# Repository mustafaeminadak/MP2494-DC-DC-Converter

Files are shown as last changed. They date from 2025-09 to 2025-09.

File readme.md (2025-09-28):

# MP2494 DC-DC Converter

This repository contains the hardware design files for a **DC/DC Buck Converter** based on the **MP2494 Step-Down Regulator IC**. The design focuses on **Low EMI**, **High Efficiency**, and **Reliable PCB Layout Practices** to ensure stable operation. You will find resources such as datasheets, specifications, design considerations, schematics, layouts, and 3D previews of the board.  

## 📑 Datasheet  

The MP2494 is a **monolithic step-down switch mode converter**. It delivers up to **2A continuous output current** across a wide input voltage range with excellent load and line regulation.  

- Features low EMI signature with controlled switching edges.  
- Built-in protections: **cycle-by-cycle current limiting** and **thermal shutdown**.  
- Requires only a few standard external components.  
- Available in **SOIC8** and **SOIC8E** packages.  

The MP2494 uses a **current-mode control architecture**:  
- At the start of a cycle, the switch turns on, connecting the inductor to the input supply.  
- The inductor current is sensed and compared with the Error Amplifier output.  
- When the sensed current exceeds the control threshold, the switch is turned off.  
- A Schottky diode carries inductor current during the off cycle.  

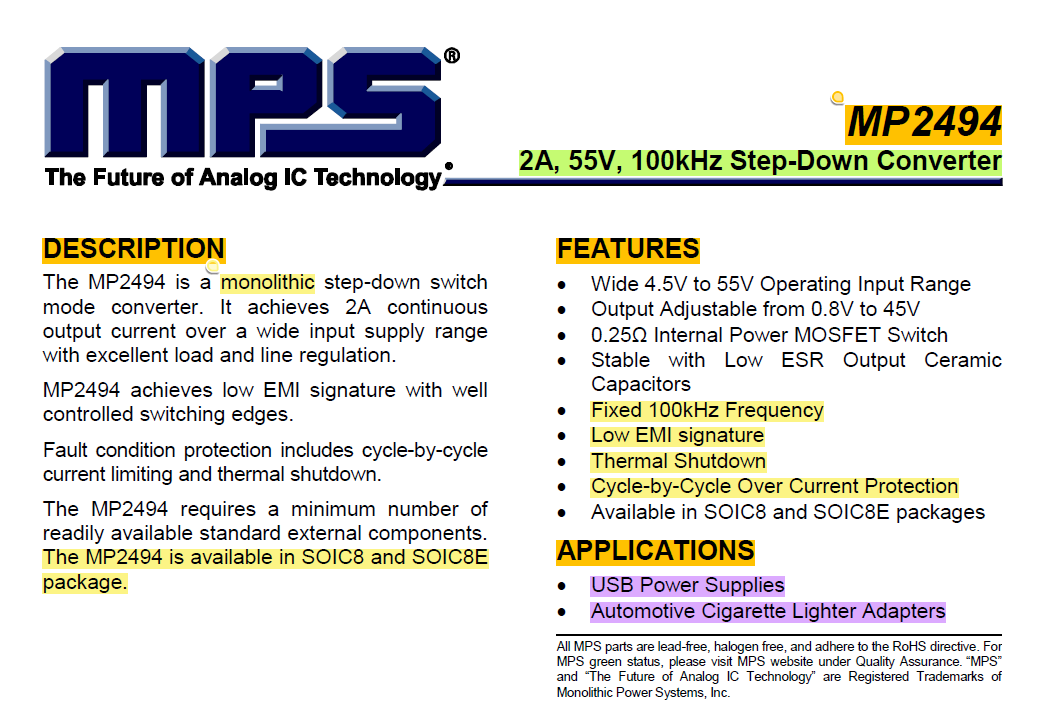
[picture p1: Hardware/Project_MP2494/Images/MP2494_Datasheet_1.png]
Datasheet Diagram_1

##
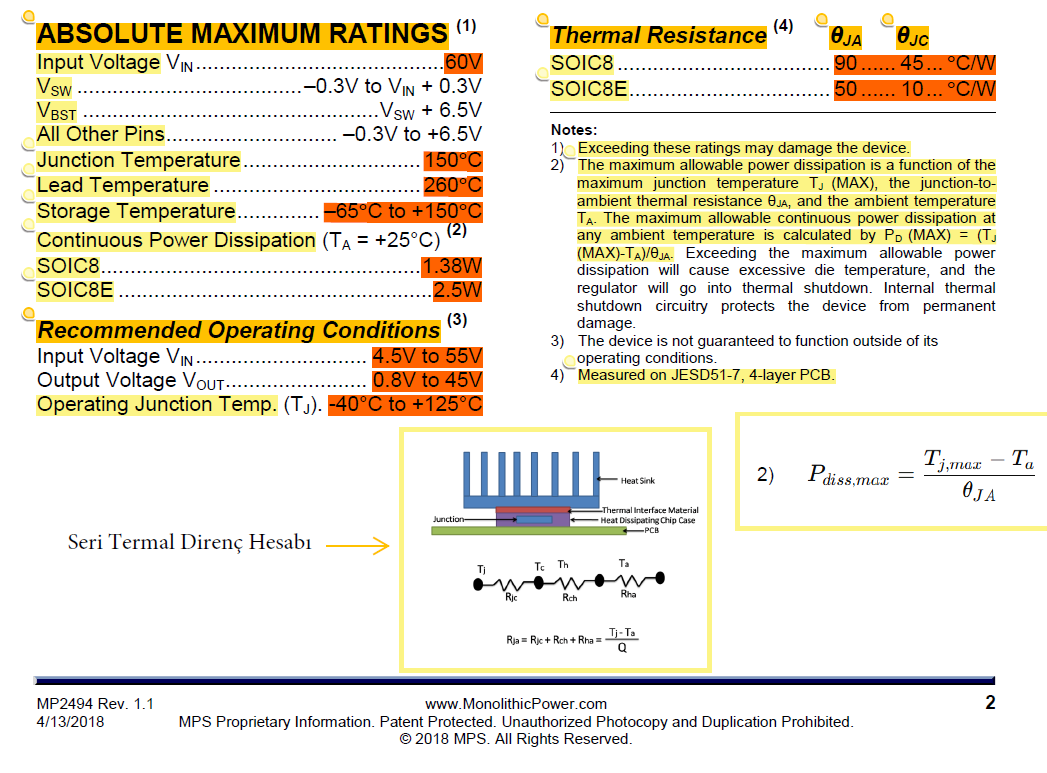
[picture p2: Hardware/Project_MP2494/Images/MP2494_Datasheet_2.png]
Datasheet Diagram_2


## ⚙️ Specifications

* Input Voltage Range: **10V – 48V**
* Nominal Voltage: **12V**
* Output Voltage: **5V**
* Output Current: **2A**
* Switching Frequency: **100kHz (typical)**
* Inductor Ripple Current: **38%**
* Slew Rate of Transient: **1 A/µs**
* Protection: **OCP, Thermal Shutdown**
* Efficiency (measured): **~85.75%**

# MPS Design Tool Simulation
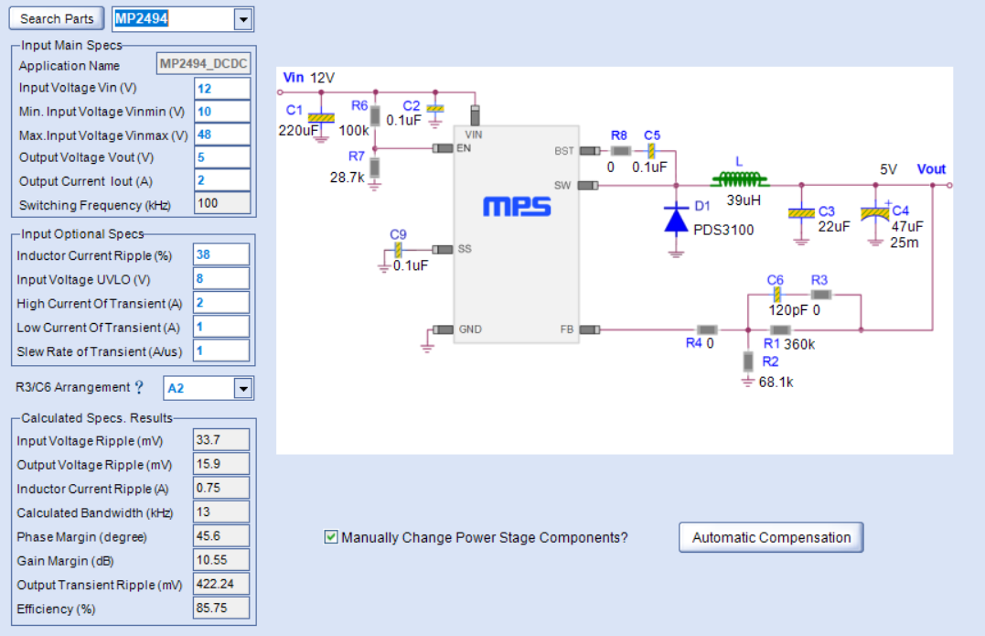
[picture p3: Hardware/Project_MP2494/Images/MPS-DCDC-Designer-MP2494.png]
Specifications


## 🛠️ Design Considerations

When designing the PCB, follow these layout guidelines for stable operation and reduced EMI:

1. Place the **input capacitor** and **freewheel diode** on the same PCB layer as the IC and as close as possible to the IC pins.
2. Use **thermal vias** if necessary to improve heat dissipation.
3. Place the **inductor close to the IC**, but it does not need to be as close as the input capacitor. Keep copper area for the switching node minimal to reduce noise radiation.
4. Place the **output capacitor close to the inductor**.
5. Keep the **ground return path** away from noise-sensitive components.

Additional Notes:

* For mounting holes, GND connection depends on mechanical and shielding needs.
* Edge plating is not required for all boards but can help in high-current, EMI-sensitive designs.
* The EN pin can be tied to VIN (always-on) or controlled via a resistor divider (optional R7).

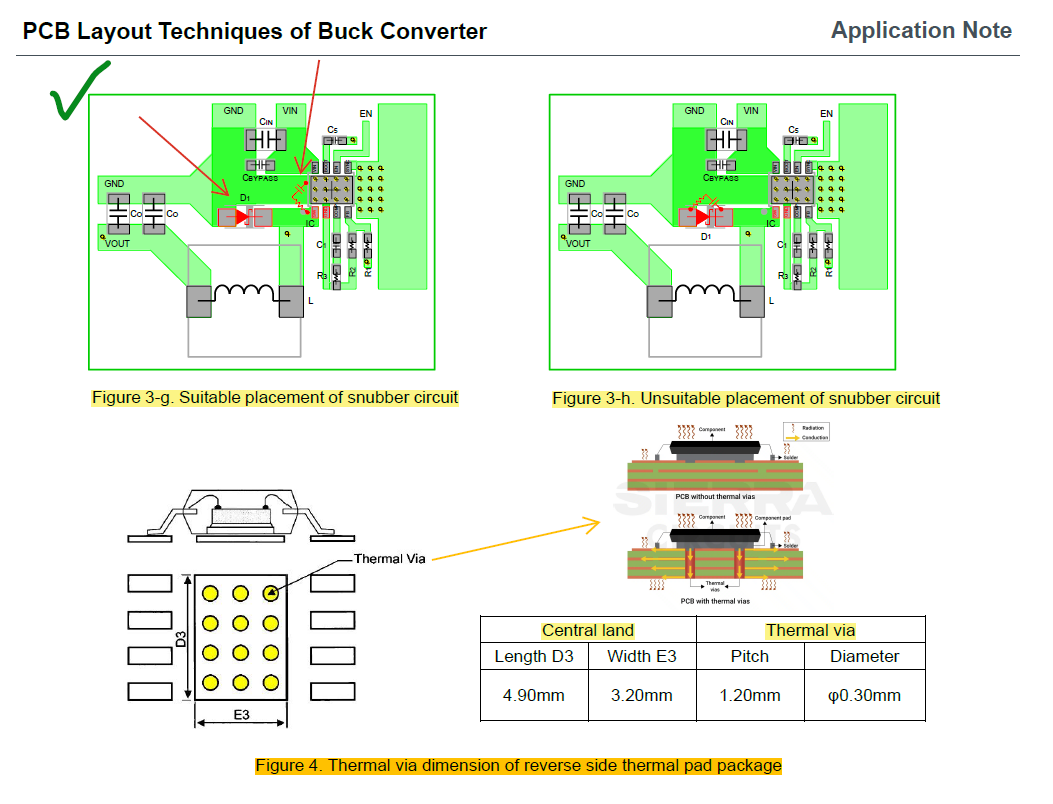
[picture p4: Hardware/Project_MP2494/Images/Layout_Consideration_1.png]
Layout Considerations_1

##
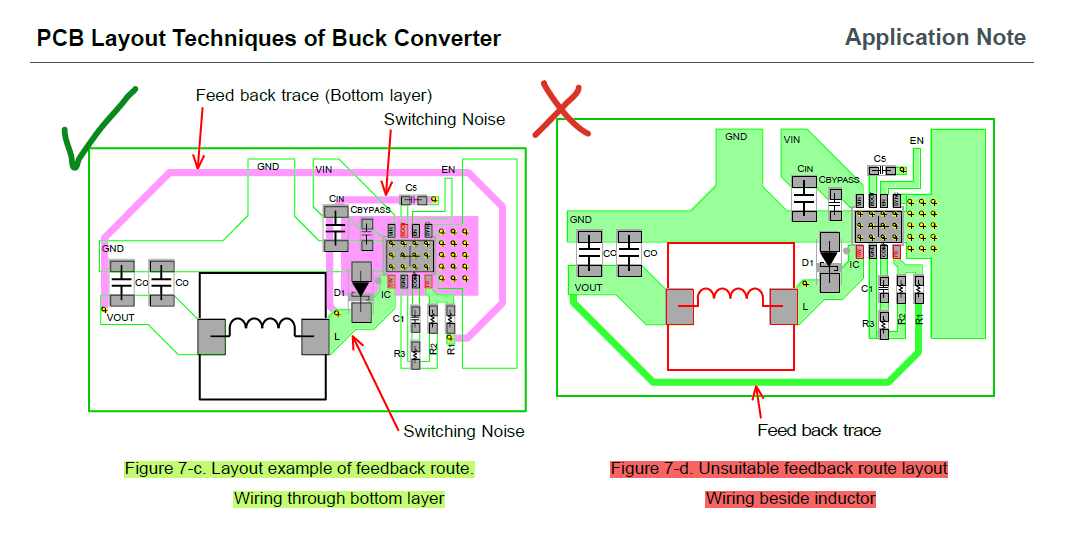
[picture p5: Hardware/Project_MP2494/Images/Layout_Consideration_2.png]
Layout Considerations_2

##
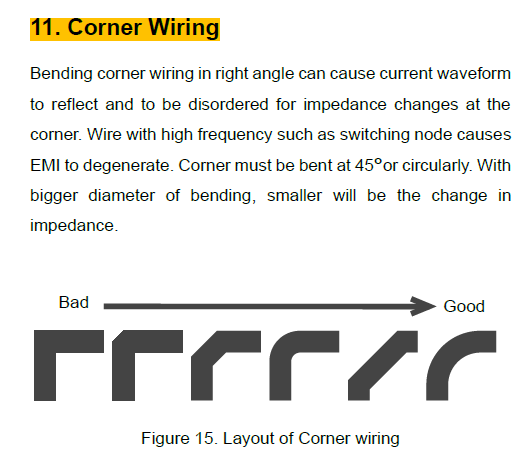
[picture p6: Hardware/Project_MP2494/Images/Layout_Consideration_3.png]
Layout Considerations_3


## 📐 Schematic

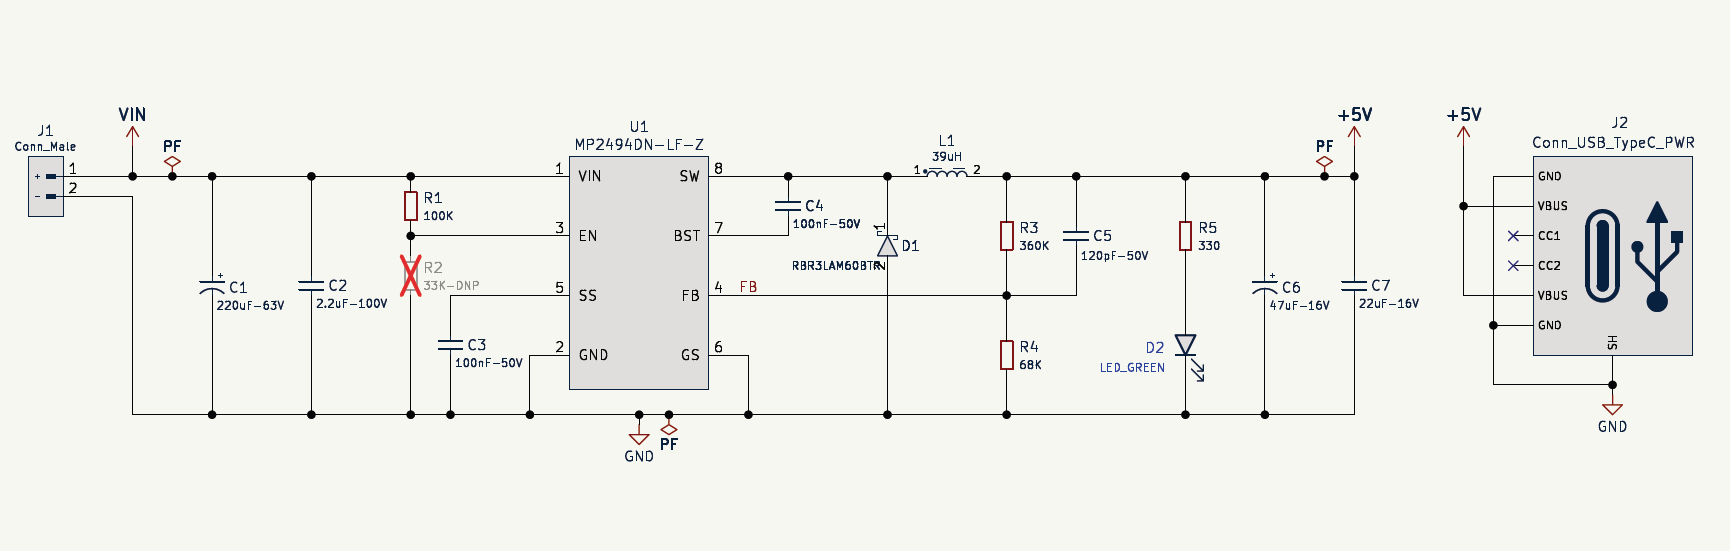
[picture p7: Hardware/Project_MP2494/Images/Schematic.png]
Schematic


## 🧩 Layout

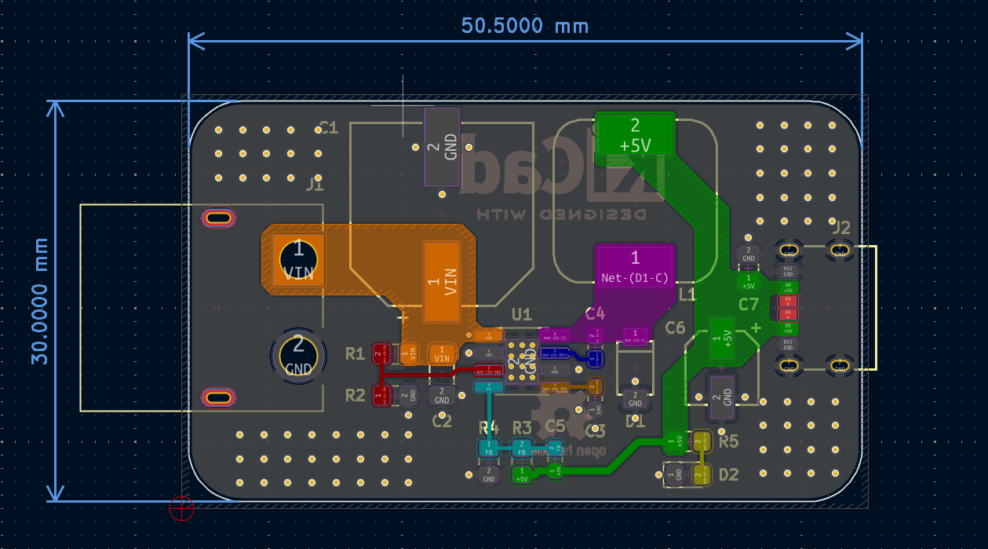
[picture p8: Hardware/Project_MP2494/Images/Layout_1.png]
Layout_1

##
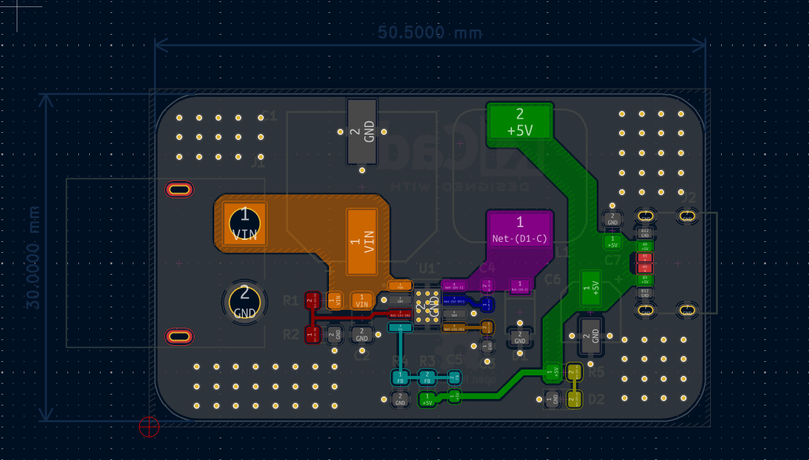
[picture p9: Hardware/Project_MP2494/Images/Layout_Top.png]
Layout_2

##
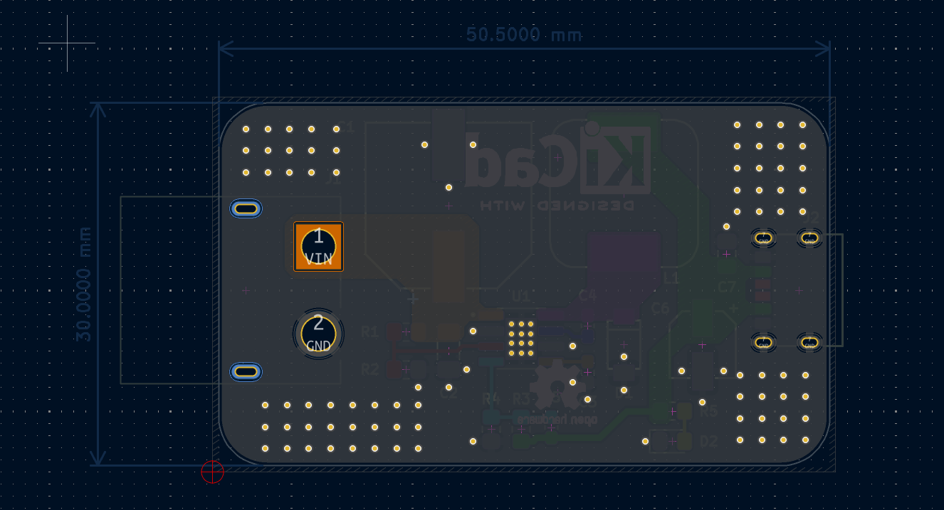
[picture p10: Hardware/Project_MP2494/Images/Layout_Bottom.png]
Layout_3


## 🎨 3D View

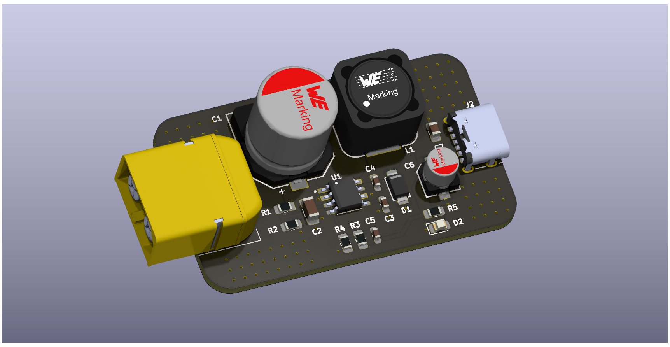
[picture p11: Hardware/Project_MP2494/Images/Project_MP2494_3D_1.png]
3D_View_1

##
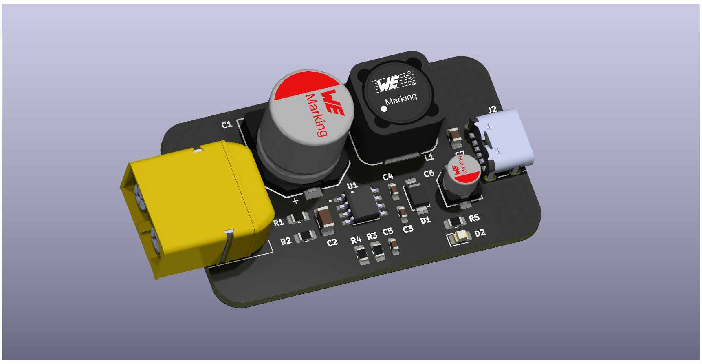
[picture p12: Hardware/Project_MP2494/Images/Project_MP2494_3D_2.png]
3D_View_2


## 📌 Notes

* Efficiency achieved: **~85.75%** (very good for this design).
* Mounting hole GND connection is optional, depending on mechanical and EMI needs.
* R7 is optional: if EN pin should be always active, tie directly to VIN.
* Edge plating is not mandatory unless your design requires **high shielding or structural robustness**.

## 🏭 Manufacturing

The PCB for this project can be fabricated using standard FR4 process.  
Gerber files are provided in the repository for direct upload to PCB manufacturers.

For interactive inspection of the Gerber layers, you can use **PCBWay Online Gerber Viewer**:  



Simply click the button above and upload the provided Gerber `.zip` file to view all PCB layers online.

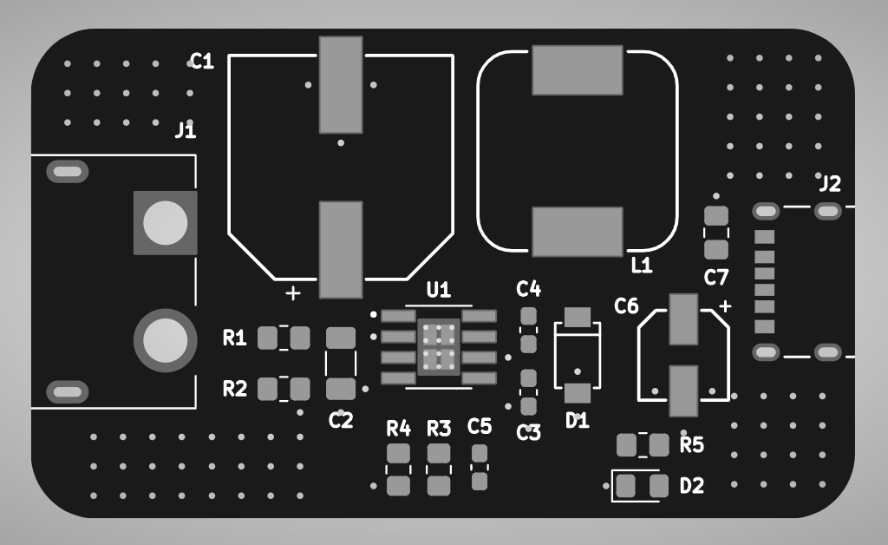
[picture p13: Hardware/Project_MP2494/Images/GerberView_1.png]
Gerber View_1

##
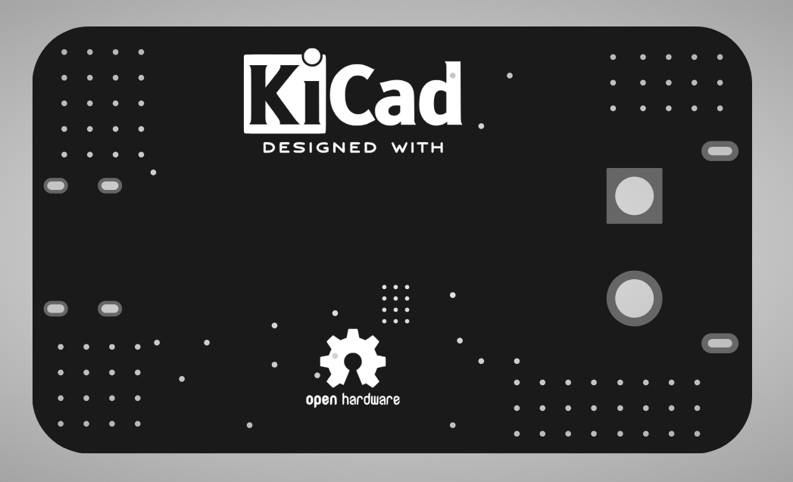
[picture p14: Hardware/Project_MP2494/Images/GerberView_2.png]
Gerber View_1


## 📜 License 
This project is released under the MIT License.

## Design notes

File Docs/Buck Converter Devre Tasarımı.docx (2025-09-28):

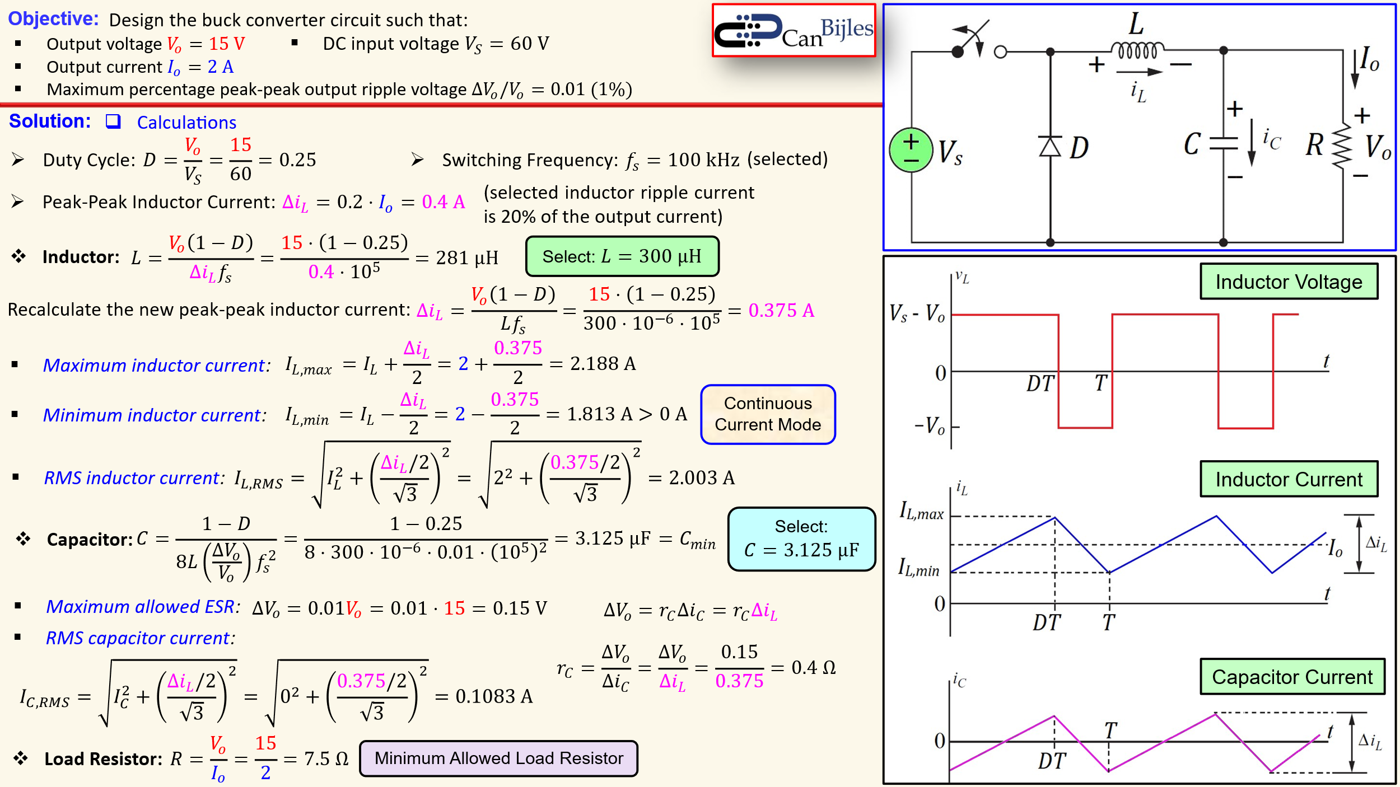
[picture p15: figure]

Buck Converter Devre Tasarımı (CCM Mode)

Örnek Tasarım

VIN = 15V (Nominal), VOUT = 5V (Nominal), Power Out = 10W (Nominal), Efficiency > 90%, FS = 500kHz, ΔVo/Vo = 0.01 (%1)

1. Çıkış Akımı (Output Current)

I_(OUT) =(10W)/(5V)=2A

2. Görev Döngüsü (Duty Cycle)

V_(OUT) = V_(IN) x D (Duty Cycle)

D=(V_(OUT))/(V_(IN))=(5V)/(15V)=1/3≈0.33

3. İndüktör Ripple Akımı (Inductor Ripple Current)-1

ΔI_L =0.2 (%20) x 2A=0.4A

Maksimum İndüktör Akımı: I_(L, max) = I_L + (ΔI_L)/2=2A+0.2A=2.2A

Minimum İndüktör Akımı: I_(L, min) = I_L - (ΔI_L)/2=2A-0.2A=1.8A

RMS İndüktör Akımı: I_(L, rms) = √(I_L^2 +((ΔI_L /2)/(√3))^2)= √(2^2 +(0.2/(√3))^2)≈2.003A

4. İndüktör Değeri (Inductor Value)

L=(V_(OUT) x (1-D))/(f_S x ΔI_L) veya L=(V_(OUT) x (V_(IN) -V_(OUT) ))/(f_S x ΔI_L x V_(IN)) L=(5V x 2/3)/(500 x 10^3 Hz x 0.4A)≈16.6µH

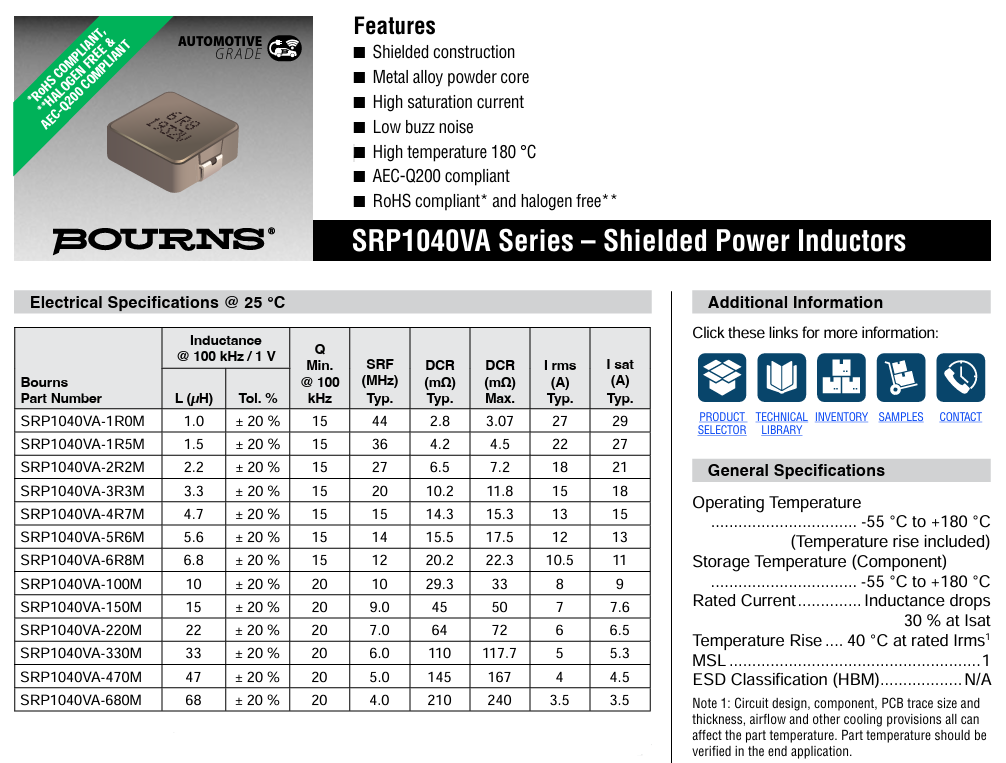
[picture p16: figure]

Yaptığımız hesaplamalara göre 16.6uH’lik bir indüktör seçimi yapmamız gerekiyor fakat bazen hesaplama sonucu elde ettiğimiz değerler ürün kataloğunda standart olarak bulunmayabilir. Bu durumda ya kendi indüktörümüzü tasarlamamız gerekir ya da bulduğumuz değere en yakın komponenti seçmemiz gerekir. Görselde de görüleceği üzere 15-22uH’lik seçenekler mevcuttur. 15uH’lik indüktörün avantajı daha düşük doğru akım direncine (DC Resistance) sahip olmasıdır. Bu durum verimlilik açısından avantaj sağlar. Fakat normal hesaba göre daha fazla ripple akımı oluşmasına sebep olacaktır. Tam tersi şekilde 22uH’lik indüktörün avantajı da normalden daha az ripple akımı fakat 15uH indüktöre göre daha az verimliliktir. Burada uygulama açısından hangisinin daha önemli olduğunu analiz etmeli ve buna göre seçim yapmalıyız.

22uH değerine sahip SRP1040VA-220M’yi seçtiğimiz durumda tekrardan ripple akımı hesabı yapmamız gerekir. Bu hesaplama SRP1040VA-150M seçildiği durumda da geçerlidir.

5. İndüktör Ripple Akımı (Inductor Ripple Current)-2

ΔI_L =(V_(OUT) x (1-D))/(L x f_S)=(5V x (1-1/3))/(22 x 10^(-6) H x 500 x10^3 Hz)≈0.303A

Maksimum İndüktör Akımı: I_(L, max) = I_L + (ΔI_L)/2=2A+(0.303A)/2≈2.151A

Minimum İndüktör Akımı: I_(L, min) = I_L - (ΔI_L)/2=2A-(0.303A)/2≈1.848A

RMS İndüktör Akımı: I_(L, rms) = √(I_L^2 +((ΔI_L /2)/(√3))^2)= √(2^2 +(0.1515/(√3))^2)≈2.002A

6. Kapasitör Değeri (Capacitor Value)

C=(1-D)/(8 x L x (ΔV_O)/(V_O) x f_S^2)=(1-(1/3))/(8 x 22 x 10^(-6) H x 0.01 x (500 x10^3 Hz)^2)≈1.515µF (C_(Min) )

Son adımda hesaplanan kapasitör değeri (1.515uF), standart değerler göz önüne alındığında 1.5uF’lık bir kapasitör seçimi gerçekleştirilebilir.

7. Maksimum İzin Verilen ESR (Maximum Allowed ESR)

ΔV_O =0.01 x V_O (5V)=0.05V

ΔV_O = r_C x ΔI_C = r_C x ΔI_L

r_C =(ΔV_O)/(ΔI_C)=(ΔV_O)/(ΔI_L)=(0.05V)/(0.303A)≈0.165Ω

RMS Kapasitör Akımı: I_(C, rms) = √(I_C^2 +((ΔI_L /2)/(√3))^2)= √(0^2 +(0.1515/(√3))^2)≈0.087A

8. Yük Direnci (Load Resistor)

R_L =(V_O)/(I_O)=(5V)/(2A)=2.5Ω

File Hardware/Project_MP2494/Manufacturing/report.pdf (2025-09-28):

## HQDFM Design for Manufacture(DFM) Report

### File name: 0000A545217_1

Time: 2025-09-28Layer count:2 | PCB Thickness: 1.60 | Quantity: 5
mm

Approved items

Urgent Issues

Issue Items
24

3
0
Basic Board Specs | Trace Width/Spacing | 10.00/8.00mil+
| Milling Density | 106.3175m/m²
| Surface Finish Area | 17.06%
| Test Point Count | 53

The file size is small, which can affect the surface mount assembly process. It is recommended to have a size larger than 7*7cm. You can optimize the size by adding a process edge or increasing the panelization.

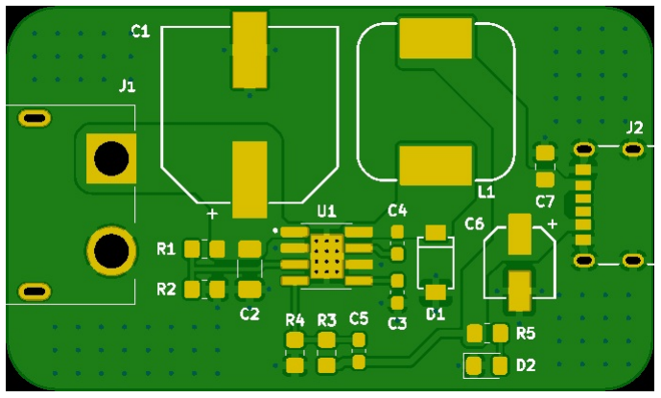
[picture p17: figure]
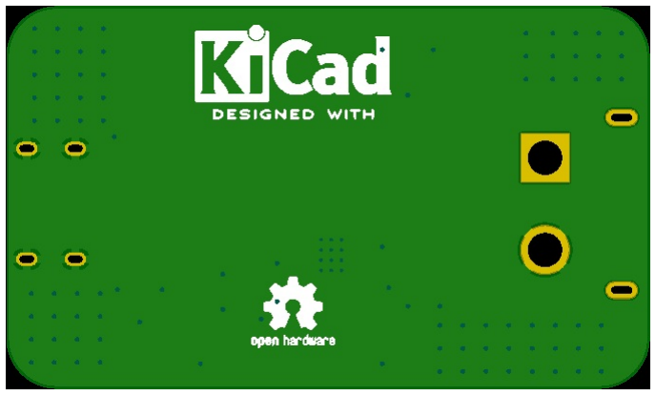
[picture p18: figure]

Type | Category | No. of Checks | Result
| Smallest Trace Width | 1 | Pass
| Smallest Trace Spacing | 3 | Pass 53
| SMD Pad Spacing | 2 | Pass 11
| Pad Size | 3 | Pass 5
| Hatched Copper Pour | 2 | Pass
| Annular Ring Size | 2 | Pass 2
| Drill to Copper | 5 | Pass 15
| Signal Integrity | 4 | Pass
| Copper-to-Board Edge | 2 | Fail 16
| Holes on SMD Pads | 4 | Pass
| Open/Shorts (IPC) | 1 | Fail
PCB Drilling Analysis | Drill Diameter | 8 | Pass 32 , Fail 2
| Drill Hole Density | 1 | Pass
| Drill Diameter | 8 | Pass 32 , Fail 2
| Drill Spacing | 4 | Pass
| Drill to Board Edge | 4 | Pass
| Drill Hole Density | 1 | Pass
| Special Drill Holes | 2 | Pass
PCB Solder Mask Analysis | Solder Mask Dam | 2 | Pass 13
| Missing SMask Opening | 1 | Pass
PCB Silk Analysis | Silkscreen Spacing | 1 | Pass
PCBA Fiducial Analysis | Fiducial Count | 1 | Pass

PCB Trace Analysis

ID | Check | Limits | Value | Issue | Image | Position | Qty | Level

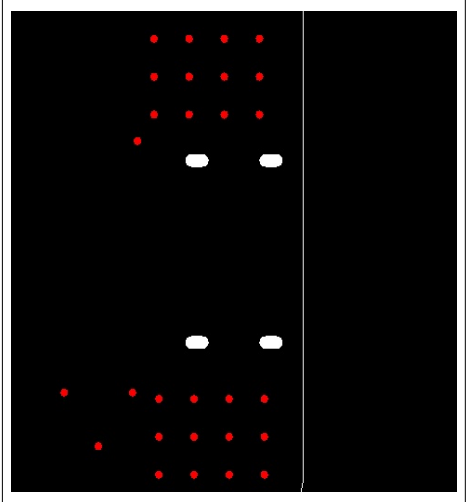
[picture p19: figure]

1

### Drill

Diameter_S
lot Aspect
Ratio

1.5,2,2

0.30

mm

Slots with aspect ratio of 2.00 were detected in your design. This could increase the risk of incomplete

### drilling of the slot, which

decrease manufacturing
efficiency and yield, and

### affect the reliability of the

boards. The ratio should be increased to at least 2:1

160.95,-110.00 | 4 | Warnin g

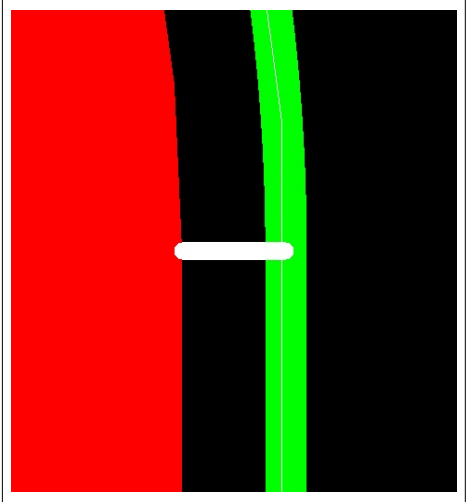
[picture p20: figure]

2

Copper-to- Board

Edge_Cop

per-to- Board

### Edge

8,15,20

0.25

mm

Copper-to-edge spacing of
9.86mil was detected in
your design.This could
increase the risk of
exposed copper on the
edge of the boards or
damaged traces/pads, which decrease

manufacturing efficiency
and yield, and affect the
reliability of the boards. It is recommended to
increase the spacing to at least 0.4 mm for edge
routing and for v-cuts (v- cut spacing may depends

on board thickness).

164.37,-98.50 | 8 | Warnin g

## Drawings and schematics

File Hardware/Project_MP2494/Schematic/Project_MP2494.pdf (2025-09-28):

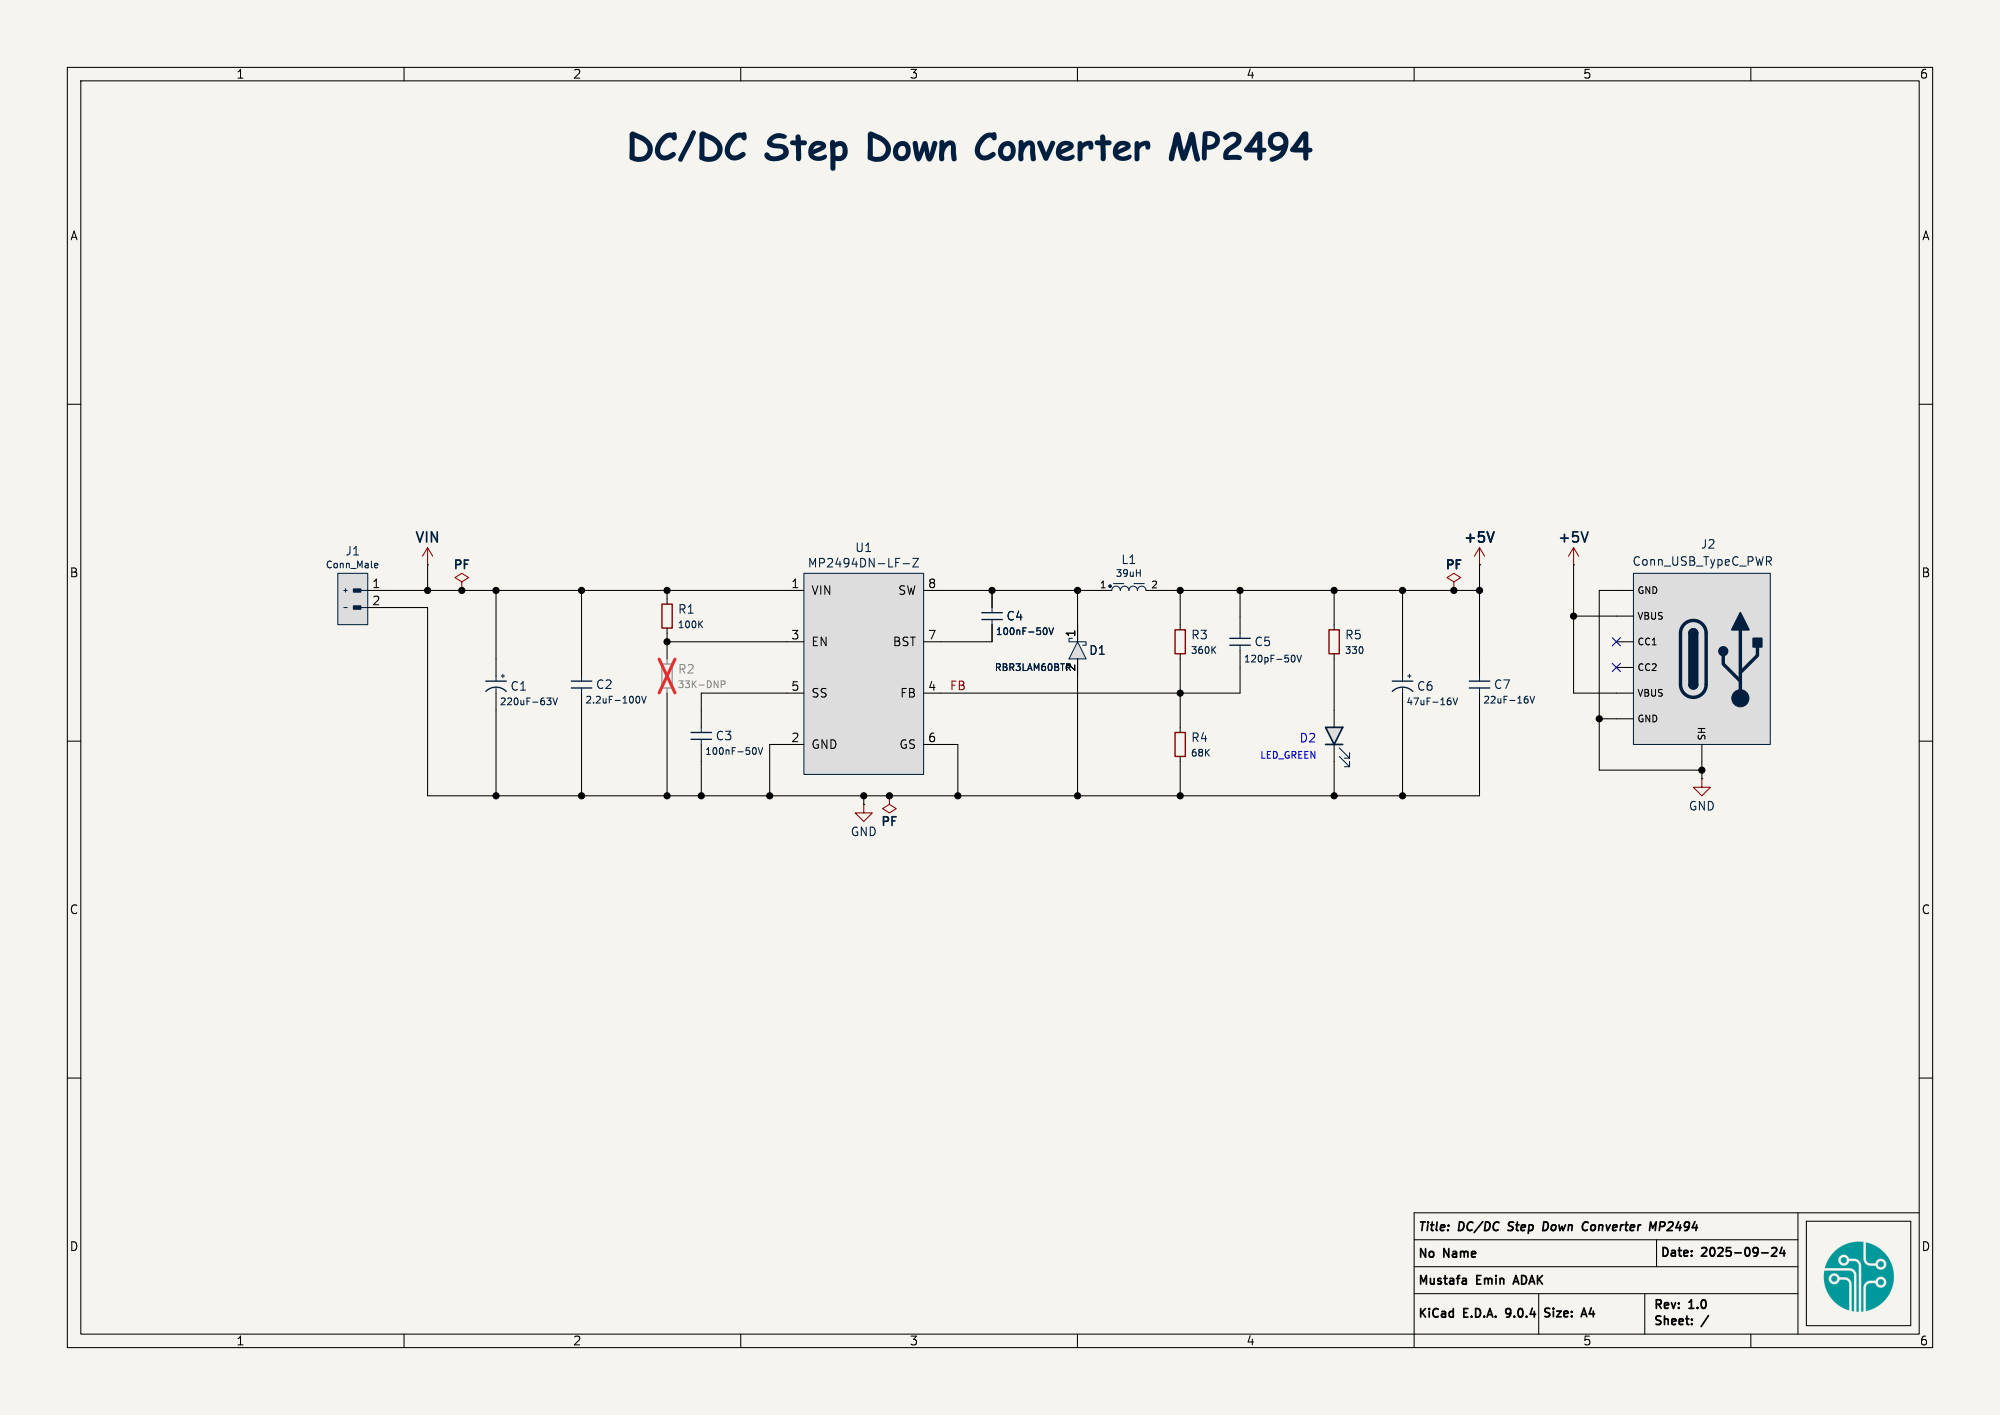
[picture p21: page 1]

FB DC/DC Step Down Converter MP2494

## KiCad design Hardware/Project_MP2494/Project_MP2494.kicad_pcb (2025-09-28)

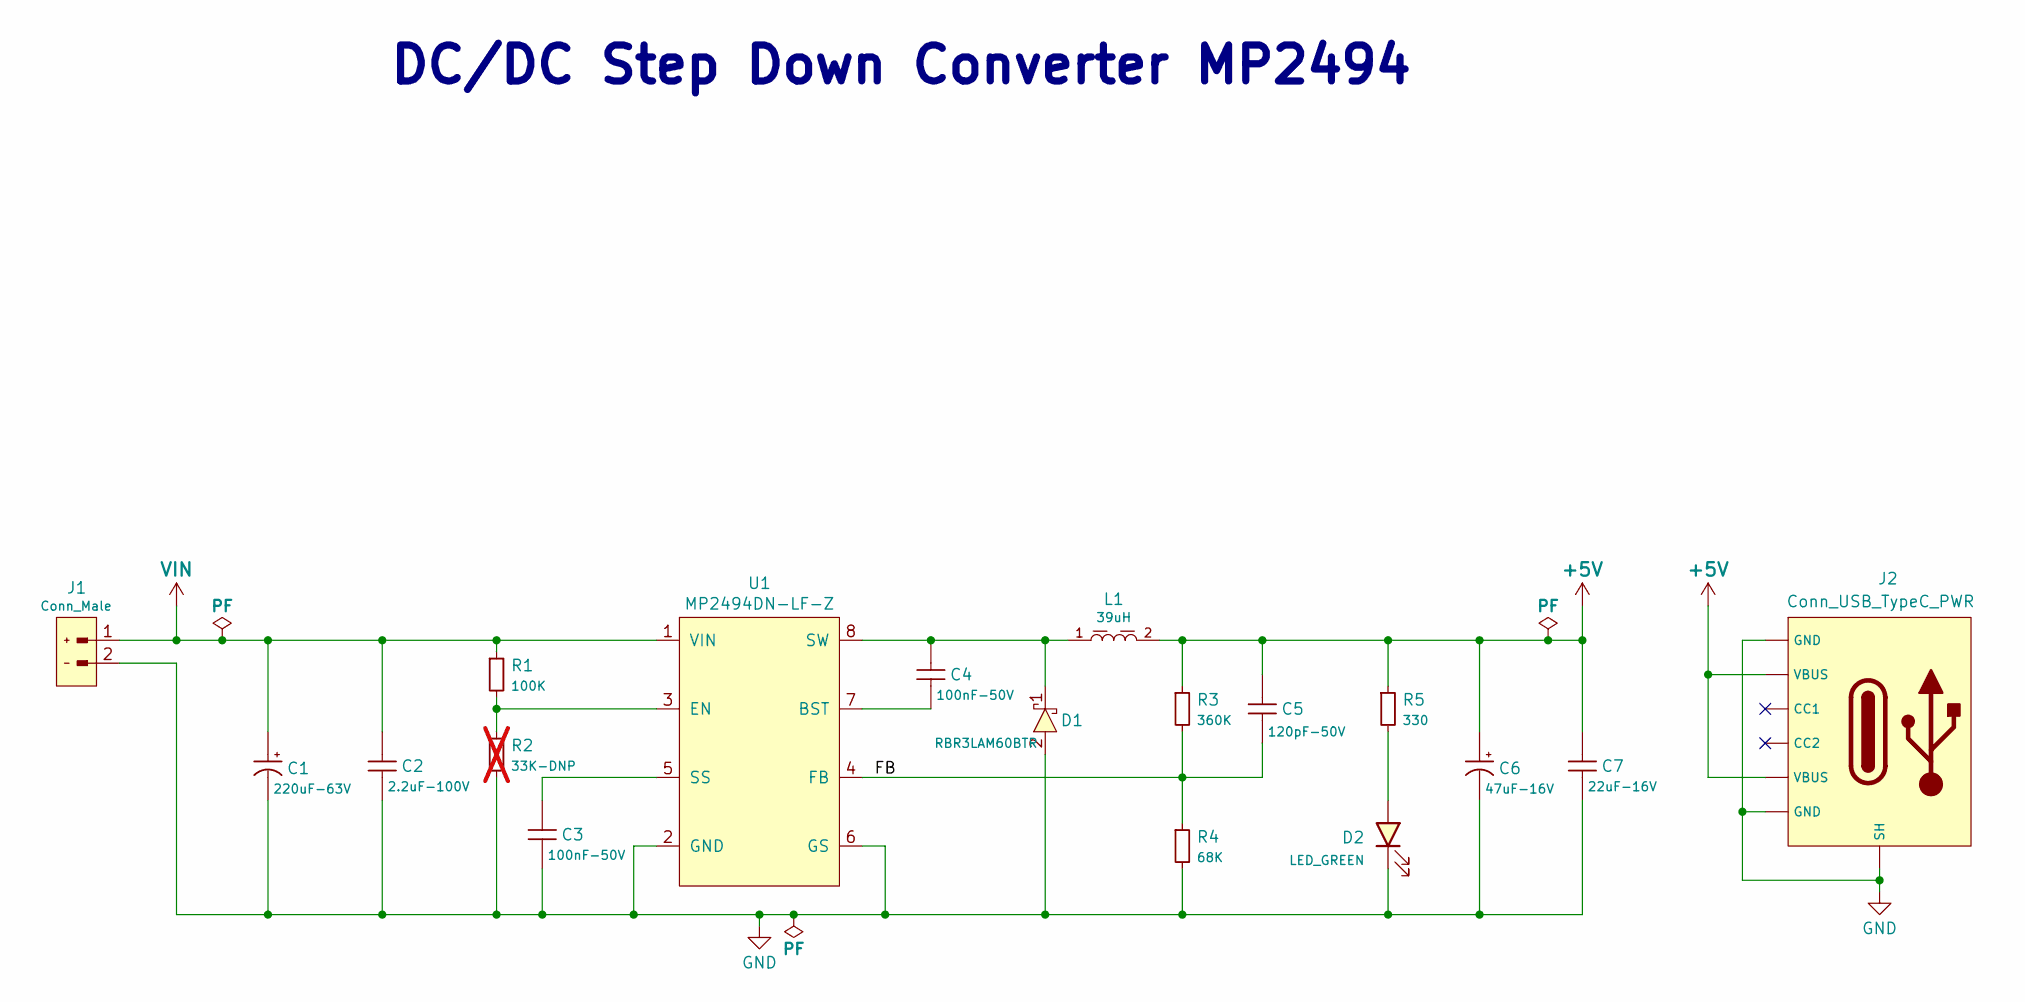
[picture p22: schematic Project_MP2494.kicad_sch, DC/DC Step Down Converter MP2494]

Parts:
C1: 220uF-63V; WCAP-ASLI_12.5X14_DXL_220U_; Part Number 865080762015
C2: 2.2uF-100V; C_1206_3216Metric_Pad1.33x1.80mm_HandSolder; Part Number CC1206KKX7R0BB225
C3, C4: 100nF-50V; C_0603_1608Metric_Pad1.08x0.95mm_HandSolder; Part Number C0603C104K5RACTU
C5: 120pF-50V; C_0603_1608Metric_Pad1.08x0.95mm_HandSolder; Part Number C0603C121K5RACAUTO
C6: 47uF-16V; WCAP-ASLI_5X5.5_DXL_47U_; Part Number 865080342006
C7: 22uF-16V; C_0805_2012Metric_Pad1.18x1.45mm_HandSolder; Part Number CC0805MKX5R7BB226
D1: RBR3LAM60BTR; DIO_RB050LAM_ROM-M
D2: LED_GREEN; LED_0805_2012Metric_Pad1.15x1.40mm_HandSolder
J1: Conn_Male; AMASS_XT60PW-M; Part Number XT60PW-M
J2: Conn_USB_TypeC_PWR; 2171750001_MOL; Part Number 2171750001
L1: 39uH; WE-PD_1210
R1: 100K; R_0805_2012Metric_Pad1.20x1.40mm_HandSolder
R2: 33K-DNP; R_0805_2012Metric_Pad1.20x1.40mm_HandSolder; not fitted
R3: 360K; R_0805_2012Metric_Pad1.20x1.40mm_HandSolder
R4: 68K; R_0805_2012Metric_Pad1.20x1.40mm_HandSolder
R5: 330; R_0805_2012Metric_Pad1.20x1.40mm_HandSolder
U1: MP2494DN-LF-Z; SOIC8E

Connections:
+5V: C5.1, C6.1, C7.1, J2.A9 (VBUS), J2.B9 (VBUS), L1.2, R3.1, R5.1
/FB: C5.2, R3.2, R4.1, U1.4 (FB)
GND: C1.2, C2.2, C3.1, C6.2, C7.2, D1.2 (A), D2.1 (K), J1.2, J2.7 (SH), J2.A12 (GND), J2.B12 (GND), R2.2, R4.2, U1.2 (GND), U1.6 (GS)
unnamed: C4.2, D1.1 (C), L1.1, U1.8 (SW)
unnamed: D2.2 (A), R5.2
unnamed: C4.1, U1.7 (BST)
unnamed: R1.2, R2.1, U1.3 (EN)
unnamed: C3.2, U1.5 (SS)
VIN: C1.1, C2.1, J1.1, R1.1, U1.1 (VIN)

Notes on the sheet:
DC/DC Step Down Converter MP2494

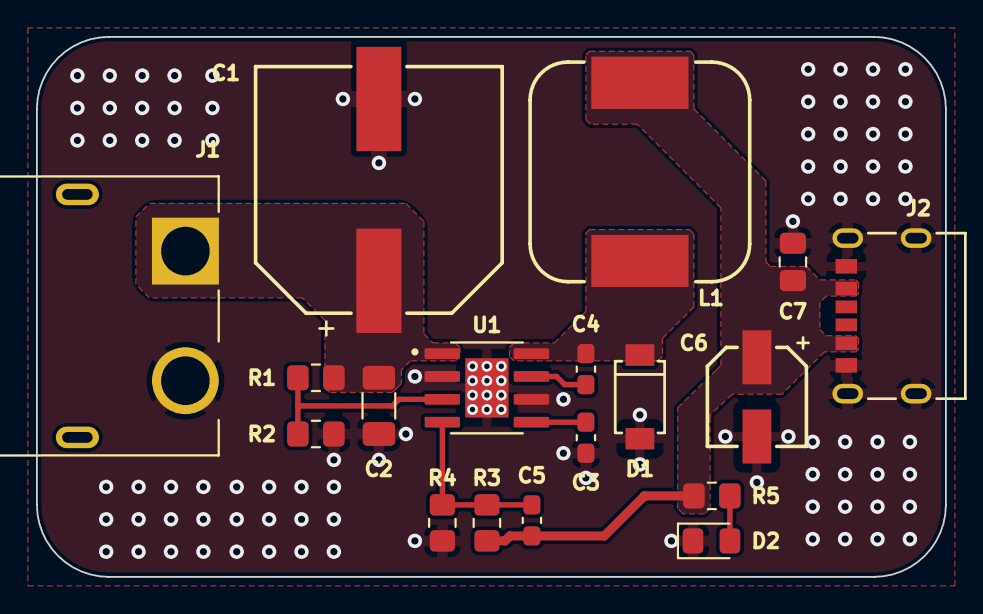
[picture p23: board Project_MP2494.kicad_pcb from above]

Board: 2 copper layers, 50.5 x 30.0 mm, 18 parts (0 on the bottom side), 9 nets.
